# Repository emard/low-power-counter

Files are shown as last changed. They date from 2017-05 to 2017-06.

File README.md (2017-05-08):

# Low power counter with ATTINY85V

Intended for counting slow pulses which
occur once in few seconds or slower.

Counter keeps its state in EEPROM
which retains data when unpowered 
(without battery).

Counts up to 4 input channels and sends
them over 1 multiplexed output line.

Runs on 3V lithium battery like CR2032.
In standby state it enters low power mode (below 1uA),
what makes a long battery life.

Everything runs on a small AVR ATTINY85V microcontroller,
a single chip in 8-pin package.

# Input and Output

It counts every transition of the input state. It will trigger
on both rising and falling edges. So it will update counter
when input changes from logical 0 to 1 and also back from 1 to 0.

Chip ATTINY85V layout

    nRESET |1  \/  8| +3V
       IN3 |2      7| IN2
       OUT |3      6| IN1
       GND |4      5| IN0

Too fast events >10Hz will not be counted, for example mechanical
contact ringing of the input switch will be filtered out.

After each input pulse, new counter state is sent over
the serial digital line. Output is a timed bit sequence 
containing header, channel number, counter value and CRC.
Output is intended to be connected to a simple
on-off keying (OOK) 433 MHz transmitter and received remotely with
some general-purpose receiver like
[rtl_433](https://github.com/merbanan/rtl_433.git)
(mostly compatible with honeywell.c protocol decoder)
see also
[ArduinoWeatherOS](https://github.com/robwlakes/ArduinoWeatherOS)
about Manchester protocol encoding.

# Power saving issues

When designing the [circuit](/circuit/schematics.pdf) 
take into account that every current flow
draws some power, so for example when internal pull-up resistors
in the chip are enabled, each input connected to GND will draw about 
80uA which can drain CR2032 battery in 3 months.
Option is to disable internal pull-up and connect external
1Mohm pull-up resistor. It will draw 3uA per grounded input pin,
but will also be more sensitive to environmental electric noise.

During 3V battery life, voltage will drop down to about 2V.
Low-voltage version of the chip "ATTINY85V" is recommended
because it is designed to work down to 1.8V.
Normal "ATTINY85" is designed down to 2.7V but it 
seems to work at 2V though.

The output transmitter should also be designed to work with
battery voltage below 2V and have low power mode when idle.
SYN115 433MHZ ASK Transmitter Module works well.

# Todo

    [ ] Reset all counters with nRESET
    [ ] Battery voltage monitoring

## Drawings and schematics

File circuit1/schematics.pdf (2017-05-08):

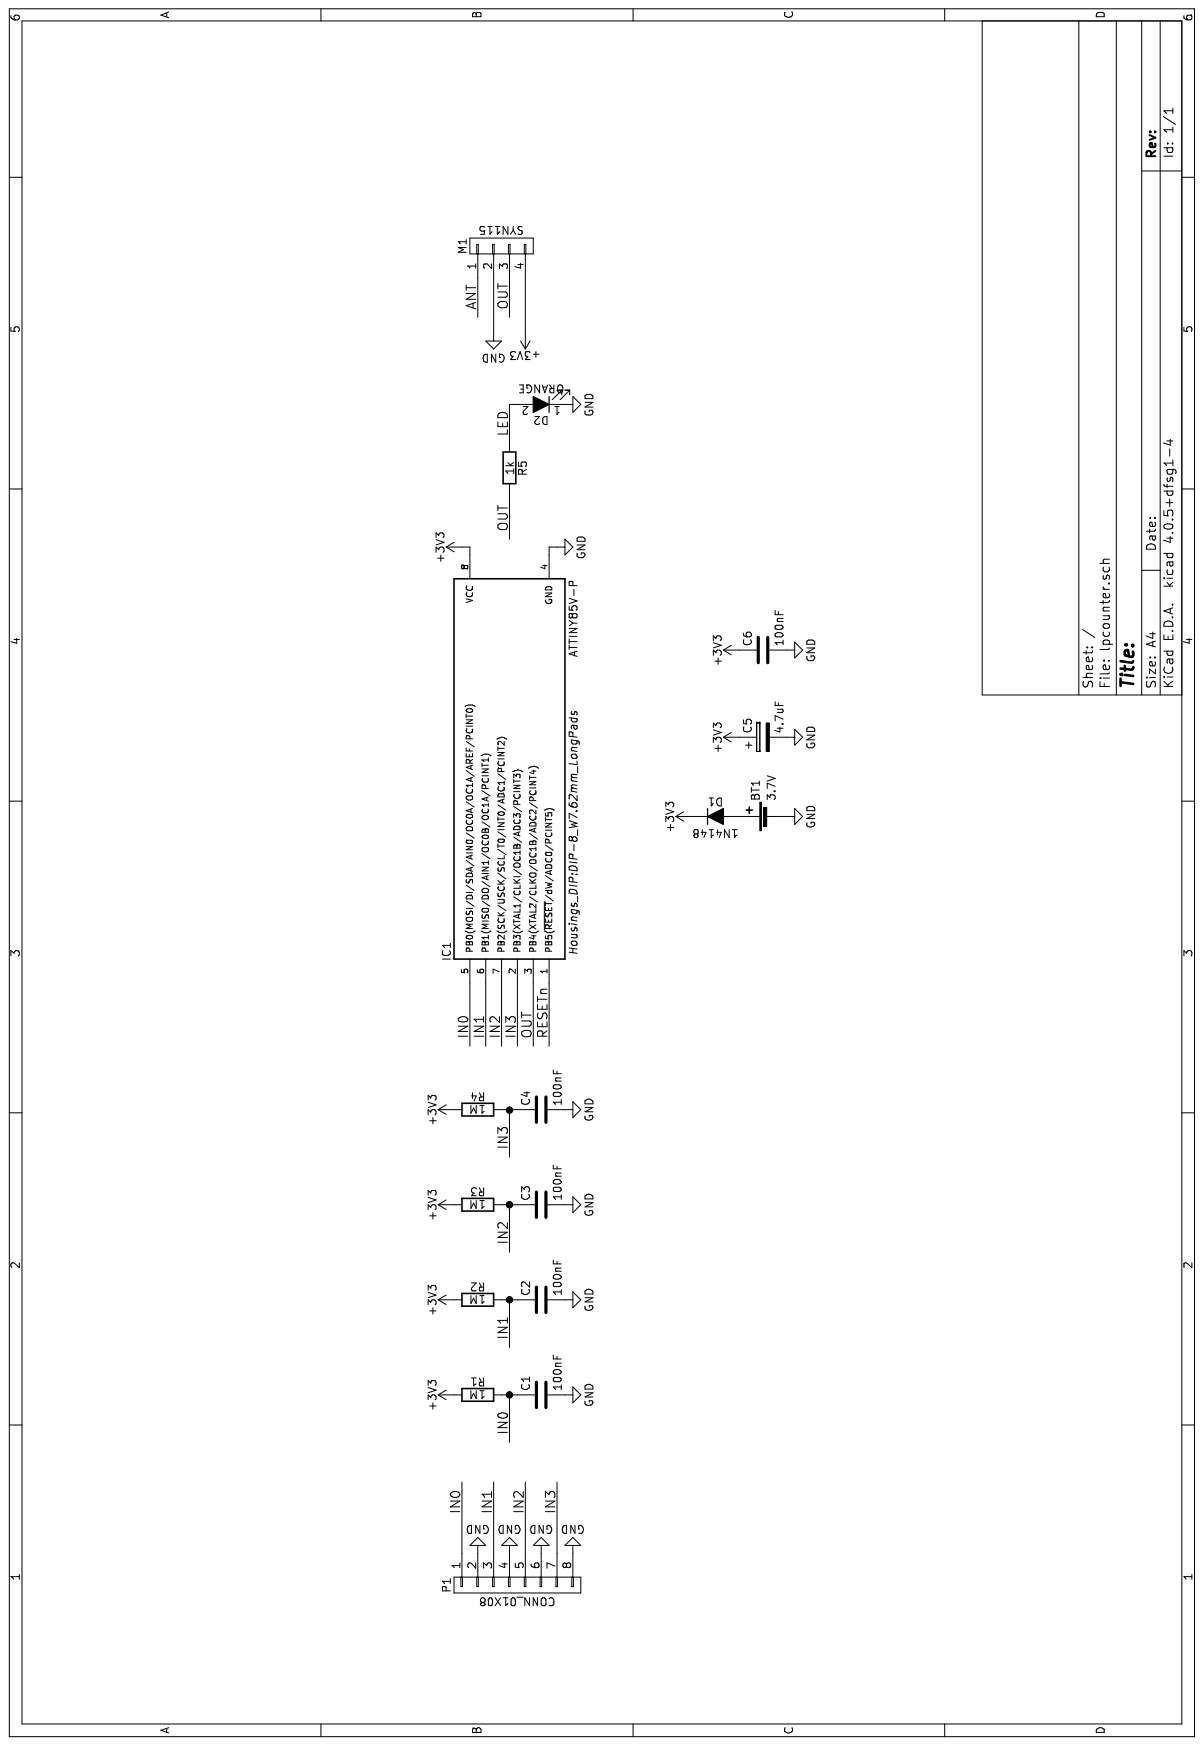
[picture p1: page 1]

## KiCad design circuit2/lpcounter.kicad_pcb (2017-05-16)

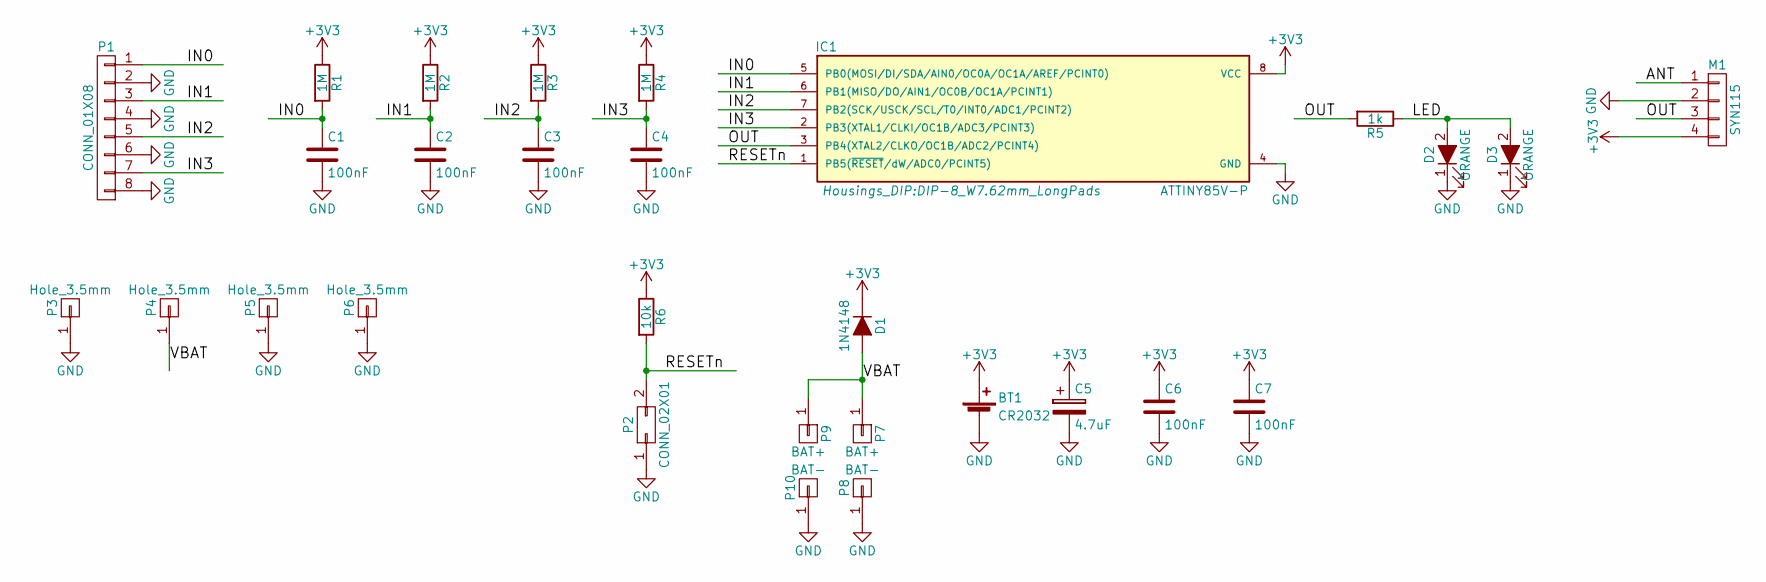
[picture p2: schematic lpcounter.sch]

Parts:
BT1: CR2032; Keystone_106_1x20mm-CoinCell
C1, C2, C3, C4, C6, C7: 100nF; C_1206_HandSoldering
C5: 4.7uF; Tantalum_Case-U_EIA-6032-15_Hand
D1: 1N4148; MiniMELF_Handsoldering
D2: ORANGE; LED-5MM
D3: ORANGE; LED_1206
IC1: ATTINY85V-P; DIP-8_W7.62mm_LongPads
M1: SYN115
P1: CONN_01X08; PhoenixContact_MSTBVA-G_08x5.08mm_Vertical
P2: CONN_02X01; Pin_Header_Straight_1x02
P3, P4, P5, P6: Hole_3.5mm; MountingHole_3.5mm_Pad
P7, P9: BAT+; Pin_Header_Straight_1x01
P8, P10: BAT-; Pin_Header_Straight_1x01
R1, R2, R3, R4: 1M; R_1206_HandSoldering
R5: 1k; R_1206_HandSoldering
R6: 10k; R_1206_HandSoldering

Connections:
+3V3: BT1.1 (+), C5.1, C6.1, C7.1, D1.1 (K), IC1.8 (VCC), M1.4, R1.1, R2.1, R3.1, R4.1, R6.1
/ANT: M1.1
/IN0: C1.1, IC1.5 (PB0(MOSI/DI/SDA/AIN0/OC0A/OC1A/AREF/PCI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), P1.1, R1.2
/IN1: C2.1, IC1.6 (PB1(MISO/DO/AIN1/OC0B/OC1A/PCINT1)), P1.3, R2.2
/IN2: C3.1, IC1.7 (PB2(SCK/USCK/SCL/T0/INT0/ADC1/PCINT2)), P1.5, R3.2
/IN3: C4.1, IC1.2 (PB3(XTAL1/CLKI/OC1B/ADC3/PCINT3)), P1.7, R4.2
/LED: D2.2 (A), D3.2 (A), R5.1
/OUT: IC1.3 (PB4(XTAL2/CLKO/OC1B/ADC2/PCINT4)), M1.3, R5.2
/RESETn: IC1.1 (PB5(~RESET~/dW/ADC0/PCINT5)), P2.2, R6.2
/VBAT: D1.2 (A), P4.1, P7.1, P9.1
GND: BT1.2 (-), C1.2, C2.2, C3.2, C4.2, C5.2, C6.2, C7.2, D2.1 (K), D3.1 (K), IC1.4 (GND), M1.2, P1.2, P1.4, P1.6, P1.8, P2.1, P3.1, P5.1, P6.1, P8.1, P10.1

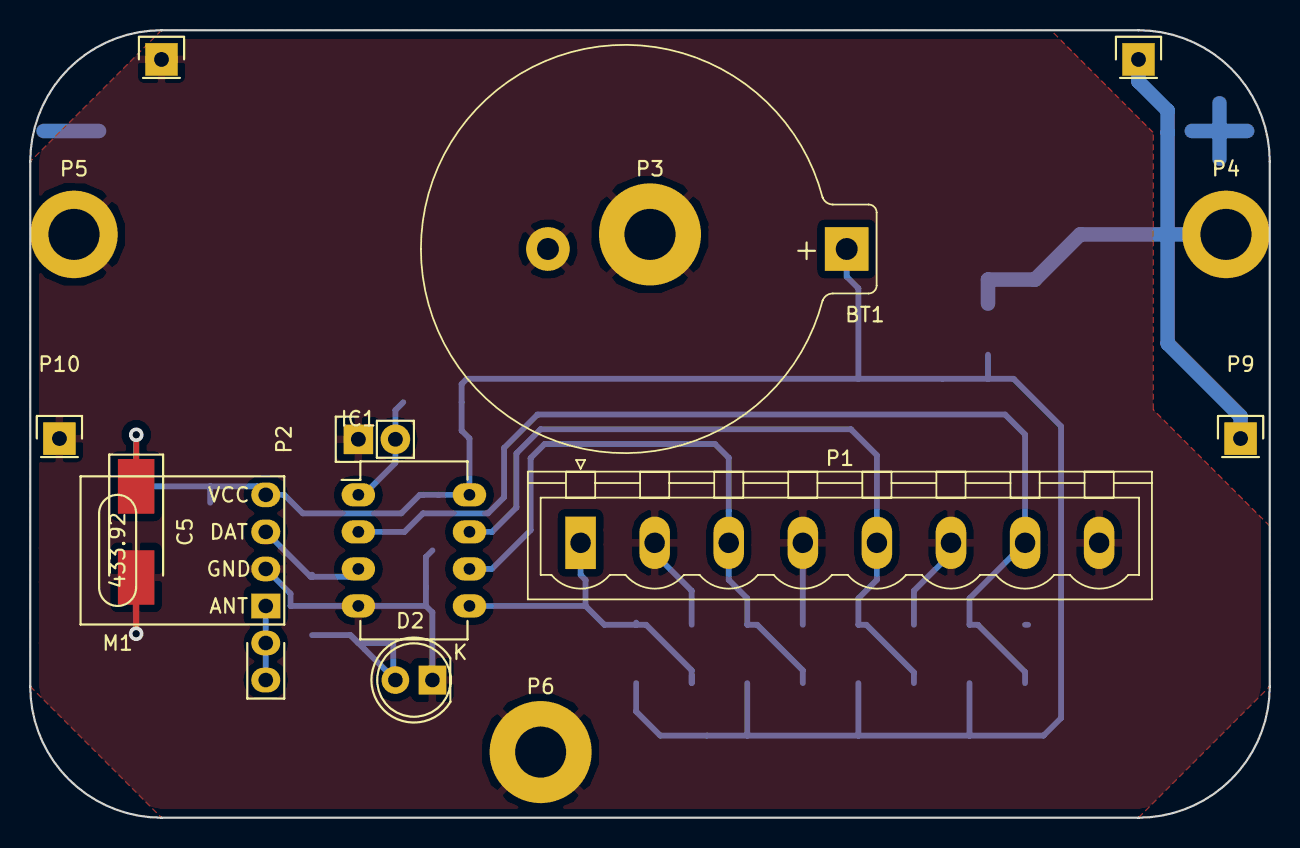
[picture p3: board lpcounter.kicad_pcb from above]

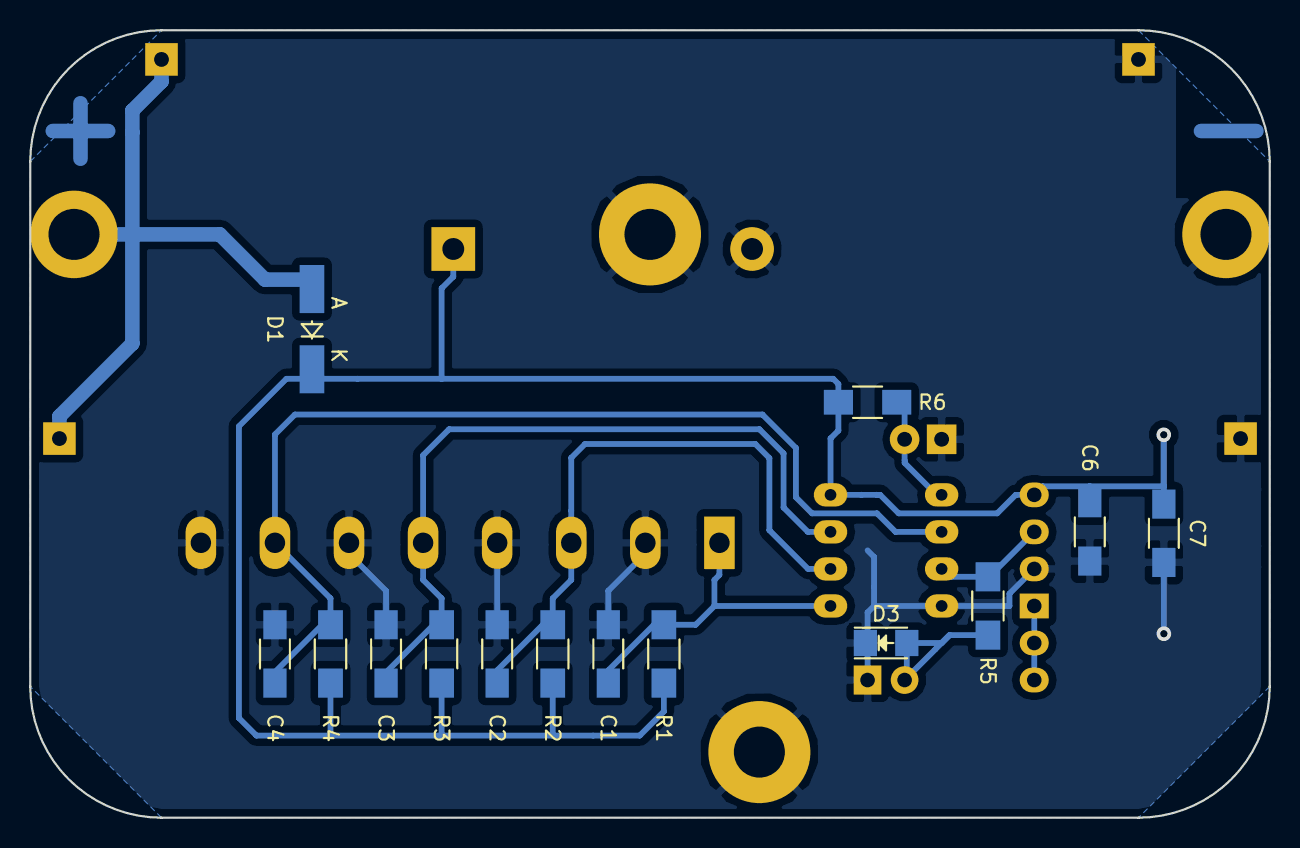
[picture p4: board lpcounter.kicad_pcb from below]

Board: 2 copper layers, 85.0 x 54.0 mm, 29 parts (14 on the bottom side), 10 nets.

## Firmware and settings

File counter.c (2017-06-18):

#include <avr/io.h> 
#include <stdlib.h>
#include <string.h>
#include <avr/interrupt.h>
#include <avr/eeprom.h>
#include <avr/sleep.h>
// #include <util/crc16.h>

#define LED (1<<PB4)
#define INPUT ((1<<PB0)|(1<<PB1)|(1<<PB2)|(1<<PB3))
#define PULLUP ((0<<PB0)|(0<<PB1)|(0<<PB2)|(0<<PB3))
#define INTERRUPT_PINS ((1<<PCINT0)|(1<<PCINT1)|(1<<PCINT2)|(1<<PCINT3))

#define ADC_DISABLE() (ADCSRA &= ~(1<<ADEN)) // disable ADC (before sleep)
#define ADC_ENABLE() (ADCSRA |= (1<<ADEN) | (1<<ADATE)) // enable continuous ADC (after sleep)
#define PIN_CHANGE_INTERRUPT_ENABLE() (GIMSK |= (1<<PCIE))
#define PIN_CHANGE_MONITOR(n) (PCMSK = n) // example: use (PCINT2 | PCINT3) to monitor PB2 and PB3 
#define PIN_CHANGE_FLAG_CLEAR() (GIFR = PCIF)

enum 
{ 
  EEPROM_BYTES = 512, // eeprom size in bytes, see datasheet
  N_CHANNELS = 4, // number of channels to track
  N_RETRANSMIT = 50, // how many times to re-transmit the message
  RETRANSMIT_DELAY1 = 200, // x100 us delay after first and subseqent odd retransmission 200->20ms
  RETRANSMIT_DELAY2 = 200, // x100 us delay after second and subsequent even retransmission 5000->500ms
  DEBOUNCE = 1000, // x100 us debounce time 200->20ms, 1000->0.1s
};

// counter data struct
struct record
{
  int32_t c[N_CHANNELS];
  uint8_t v; // battery voltage = 1.1*255/v, 77-99 high, 100-109 medium, 110-150 low
};

// calculate how many records can we store
enum
{
  N_RECORDS = EEPROM_BYTES/sizeof(struct record),
};

struct record EEMEM memory[N_RECORDS] = // storage in EEPROM
{
   { { 0,0,0,23*20, }, 1}, // initial counter values after flashing, battery voltage nonzero
};

struct record counter[1]; // one record as counter in RAM

// encoded packet to be sent, bit-slice
union packet
{
  struct
  {
    uint64_t crc:16, data:8, serial:20, unknown:4, preamble:16;
  };
  uint64_t binary;
};

uint8_t pin_state, pin_change; // ISR tracks pin state and sets bits of pin_change to 1

void record_read(struct record *r, uint8_t i)
{
  eeprom_read_block(r, &(memory[i % N_RECORDS]), sizeof(struct record));
}

void record_write(struct record *r, uint8_t i)
{
  eeprom_update_block(r, &(memory[i % N_RECORDS]), sizeof(struct record));
}

void counter_reset()
{
  uint8_t i;
  memset(counter, 0, sizeof(struct record));
  for(i = 0; i < N_RECORDS; i++)
    record_write(counter, i);
}

// find free data in eeprom
// that's first data which has 0
// also read the last non-free record
uint8_t find_free_record(struct record *r)
{
  uint8_t i;
  uint8_t nonzero_found = 0;
  struct record data[1];
  for(i = 0; i < N_RECORDS; i++)
  {
    uint8_t j, z = N_CHANNELS;
    // eeprom_read_block(data, &(memory[i % N_RECORDS]), sizeof(struct record));
    record_read(data, i);
    for(j = 0; j < N_CHANNELS; j++)
    {
      if(data->c[j] == 0)
        z--;
    }
    // all values zero -> found new free entry
    if(z == 0)
    {
      if(nonzero_found == 1)
      {
        return i;
      }
    }
    else
    {
      nonzero_found = 1;
      if(r)
        memcpy(r, data, sizeof(struct record));
    }
  }
  return 0;
}

// interrupt service routine: PIN CHANGE 0 interrupt
// on attiny84 it covers 8 input pins PA 0-7
// there also exists PIN CHANGE 1 interrupt which
// covers another 4 input pins PB 0-3
// on attiny85 only PIN CHANGE 0 exists
ISR(PCINT0_vect)
{
  uint8_t pin_current = PINB & INPUT;
  pin_change |= pin_current ^ pin_state;
  pin_state = pin_current;
  // executing ISR will automatically clear its interrupt flag.
  // it is not neccessary to manually clear interrupt flag:
  // PIN_CHANGE_FLAG_CLEAR();
}

// store the counter using eeprom record storage
void store_counter()
{
 uint8_t j, k;

 j = find_free_record(NULL);
 record_write(counter, j);
 // next position, wraparound
 if(++j >= N_RECORDS)
   j = 0;
 // create 0-delimiter
 struct record delimiter[1];
 delimiter->v = 0;
 for(k = 0; k < N_CHANNELS; k++)
   delimiter->c[k] = 0;
 // write 0-delimiter to next position
 record_write(delimiter, j);
}

uint16_t crc16_ccitt(uint8_t const message[], unsigned nBytes, uint16_t polynomial, uint16_t init) {
    uint16_t remainder = init;
    unsigned byte, bit;

    for (byte = 0; byte < nBytes; ++byte) {
        remainder ^= message[byte] << 8;
        for (bit = 0; bit < 8; ++bit) {
            if (remainder & 0x8000) {
                remainder = (remainder << 1) ^ polynomial;
            }
            else {
                remainder = (remainder << 1);
            }
        }
    }
    return remainder;
}

void update_crc(union packet *p)
{
  uint8_t i;
  uint8_t bb[6], *b;
  b = (uint8_t *) &(p->binary);
  for(i = 0; i < 6; i++)
    bb[i] = ~b[7-i];
  p->crc = ~crc16_ccitt(bb, 6, 0x8005, 0xfffe);
}

void transmit(uint8_t i)
{
  uint8_t j;
  union packet tx;

  // Construct the 64-bit TX packet
  tx.preamble = ~0xFFFE;
  tx.unknown = ~i;
  // tx.serial = 0x55664L;
  // tx.data = 0x3F;
  // tx.crc = 0x277D;
  tx.serial = ~(counter->c[i]); // counter value
  tx.data = ~(counter->v); // battery voltage = 1.1V*255/this_value
  update_crc(&tx);

  // use timer0 
  TCNT0 = 0;
  OCR0A = 135; // us (nomial value 140 us)
  TCCR0A = 2; // ctc mode - TCNT0 runs from 0 to OCR0A
  TCCR0B = 1; // prescaler 1 (clk), 2 (clk/8), 3 (clk/64), 4 (clk/256), 5 (clk/1024)
 
  TIFR = 1<<OCF0A; // reset timer overflow interrupt flag
 
  // blink LED send binary counter, send LSB first
  for(j = 0; j < 64; j++) // send 64-bit packet manchester encoded, MSB first
  {
    // calculate LED output state in advance
    uint8_t ledstate = (tx.binary & (1ULL<<63)) != 0 ? PORTB | PULLUP | LED : (PORTB | PULLUP) & ~LED; // MSB
    while((TIFR & (1<<OCF0A)) == 0); // wait for interrupt flag
    TIFR = 1<<OCF0A; // reset timer overflow interrupt flag
    PORTB = ledstate;
    tx.binary <<= 1; // shift next bit
    while((TIFR & (1<<OCF0A)) == 0); // wait for interrupt flag
    TIFR = 1<<OCF0A; // reset timer overflow interrupt flag
    PINB = LED; // invert the led and wait again -> manchester encoding
  }
  while((TIFR & (1<<OCF0A)) == 0); // wait for interrupt flag
  TIFR = 1<<OCF0A; // reset timer overflow interrupt flag
  PORTB &= ~LED; // led OFF
}

void update_pin_state()
{
  uint8_t i;
  pin_state = 0;
  for(i = N_CHANNELS-1; i != 0xff; i--)
  {
    pin_state <<= 1;
    pin_state |= counter->c[i] & 1; // LSB of the counter is the pin state
  }
}

// delay = n * 100 us
void delay(uint16_t x100us)
{
  uint16_t j;
  TCNT0 = 0;
  OCR0A = 100; // us
  TCCR0A = 2;
  TCCR0B = 1; // prescaler 1 (clk)
 
  TIFR = 1<<OCF0A; // reset timer overflow interrupt flag
  for(j = 0; j < x100us; j++)
  {
    while((TIFR & (1<<OCF0A)) == 0); // wait for interrupt flag
    TIFR = 1<<OCF0A; // reset timer overflow interrupt flag
  }
}

void main()
{
 // as early as possible, check the MCUSR to detect external reset
 // upon external reset, reset the EEPROM counter state
 #if 0
 uint8_t mcusr = MCUSR;
 MCUSR = 0; // clear it
 if((mcusr | EXTRF) != 0) // external reset -- clear eeprom
   counter_reset();
 #endif

 ADMUX = (0<<REFS0) | (1<<ADLAR) | (12<<MUX0); // ADC measure VCC voltage against internal 1.1V reference
 // ADLAR set to left-adjust result suitable for 8-bit reading

 set_sleep_mode(SLEEP_MODE_PWR_DOWN);

 delay(10000); // wait a moment for power to become stable (switch glitch...)
 
 DDRB = LED; // only LED output, other pins input
 PORTB = PULLUP; // pullup enable on input pins, led OFF

 find_free_record(counter);
 update_pin_state(); // read pin state from last record in eeprom

 PIN_CHANGE_FLAG_CLEAR();
 PIN_CHANGE_INTERRUPT_ENABLE();
 PIN_CHANGE_MONITOR(INTERRUPT_PINS); // this is PB0-PB3 inputs
 // should already set monitored pin as input and enable its pull up
 PIN_CHANGE_FLAG_CLEAR();

 // initialize pin change, compare stored state to current state
 pin_change = (PINB & INPUT) ^ pin_state;
 
 for(;;)
 {
   #if 1
   ADC_ENABLE();
   ADCSRB = 0<<ADTS0; // for free-running mode
   uint8_t j; // loop counter
   uint8_t tx = 0; // Bitmap having '1' for each counter changed. Used ad request to transmit
   delay(DEBOUNCE); // wait for input to stabilize and ISR to set pin_change
   ADCSRA |= 1<<ADSC; // Start measuring battery voltage
   while(pin_change != 0)
   {
     uint8_t change = pin_change, m = 1; // m is shifting 1-bit bitmask
     uint8_t new_pin_state = PINB & INPUT;

     for(j = 0; j < N_CHANNELS; j++)
     {
       if( (change & m) != 0 || ((new_pin_state ^ pin_state) & m) != 0 )
       {
         counter->c[j]++;
         update_pin_state();
         if( ((new_pin_state ^ pin_state) & m) != 0)
         {
           counter->c[j]++;
           update_pin_state();
         }
         cli();
         pin_change &= ~m; // clear pin change bit (change serviced)
         sei();
         tx |= m; // request to transmit this bit
       }
       m <<= 1; // upshift mask
     }
     delay(DEBOUNCE); // wait for pins to change again
   }

   if(tx != 0)
   {
     PORTB |= LED; // wake up the transmitter
     delay(1); // 0.1 ms pulse wakeup starts
     PORTB &= ~LED;
     // while( (ADCSRA & (1<<ADSC)) != 0 ); // wait until battery voltage measurement is done 
     // ADCL reading must be before reading ADCH
     counter->v = ADCH; // reading ADCH unlocks both ADCL and ADCH
     store_counter();
     // delay(100); // wait until transmitter wakes up completely
     for(j = 0; j < N_CHANNELS; j++)
     {
       if( (tx & 1) != 0 )
       {
         int i;
         for(i = 0; i < N_RETRANSMIT; i++)
         {
           // spacing between retransmissions
           delay( (i & 1) == 0 ? RETRANSMIT_DELAY1 : RETRANSMIT_DELAY2); // 20/500 ms delay
           cli();
           transmit(j);
           sei();
         }
       }
       tx >>= 1;
     }
   }
   #else
   // this works for single counter
   counter->c[0]++;
   store_counter();
   transmit(0);
   #endif

   ADC_DISABLE();
 
   cli();
   if(1 == 1)
   {
     sleep_enable();
     sei();
     sleep_cpu();
     sleep_disable();
   }
   // if we don't have ISR registered,
   // we need to manually clear interrupt flag:
   // PIN_CHANGE_FLAG_CLEAR();
   sei();
 }
}

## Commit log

2017-04-24 untested code to wake from sleep at interrupt
2017-04-24 empty pin change interrupt service routine
2017-04-24 getting it to compile and upload to device
2017-04-24 eeprom writes something at 1st location but doesn't advance to next record
    [counter.c]
2017-04-24 device now enters power down mode, draws around 1uA
2017-04-24 pin change interrupt works on PB0 only
2017-04-25 OK, pin change wakeup seems to work. Note that weak pullup when enabled and pin held down will consume 80uA
2017-04-25 ISR is actually not needed, input switch monitoring will be slow
2017-04-25 tracking each pin, but unreliable
2017-04-25 untested attempt to use ISR to track pin change
2017-04-25 unsupported use of timer overflow to precisely time output transmit sequence
2017-04-25 good input pulse detection timer not working
    [counter.c]
2017-04-25 timer seems to work now, missing 1<<
    [counter.c]
2017-04-25 enabling and slightly bugfixing code for interrupt pin state tracking and counting
    [counter.c]
2017-04-26 untested clearing of the eeprom on external reset
    [counter.c]
2017-04-26 disabling erase counter after reset - it erases counter on every power up
    [counter.c]
2017-04-27 detect pin change during power off
2017-04-28 trying to improve speed of counting, counter loop will accumulate changes when pulses come one after another, taking de-bounce delay into account. When pulses stop coming within some delay time, it w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
2017-04-28 speeding up the timer
2017-04-29 prolong wakeup pulse to 200us and shorten retransmit pause to 15 ms
    [counter.c]
2017-04-29 delay() bugfixed to work with 16-bit paramter
    [counter.c]
2017-04-29 Issue wakeup pulse only before first transmission. Disable interrupt during transmit() to improve bit timing.
    [counter.c]
2017-04-29 configure pullup resistors for each input pin
2017-04-29 readme update, count frequency about 10Hz
2017-04-30 readme update, sume power saving tips
2017-05-02 readme update, need to monitor battery voltage
2017-05-02 battery voltage monitoring and reporting - untested
2017-05-02 fix ADC setting to measure battery voltage
    [counter.c]
2017-05-02 comments on how to calculate battery voltage
2017-05-02 comment approx battery values
2017-05-02 free running ADC
2017-05-02 clear ADCSRB register for ADC free-running
2017-05-08 Schematics and rough PCB in KiCAD
    [lpcounter.kicad_pcb, lpcounter.sch]
2017-05-08 proper battery holder for CR2032
    [lpcounter.kicad_pcb, lpcounter.sch]
2017-05-08 readme: link to schematics PDF
2017-05-08 schematics PDF
2017-05-08 updating PCB
    [lpcounter.kicad_pcb, lpcounter.sch]
2017-05-08 fully routed
    [lpcounter.kicad_pcb, lpcounter.sch]
2017-05-08 small chamges, optimizing routes
    [lpcounter.kicad_pcb]
2017-05-09 correct footprint for SYN115, 4 screw holes, optimizing PCB drawing 18650 battery outiline
    [lpcounter.kicad_pcb, lpcounter.sch]
2017-05-09 3V battery connected direct, 3.7V battery connect in series with diode 1N4147
    [lpcounter.kicad_pcb, lpcounter.sch]
2017-05-10 placeholder for both SMD and TH LED
    [lpcounter.kicad_pcb, lpcounter.sch]
2017-05-11 drawing ABC plastic box and 18650 battery footprint for possible PCB which fits in such box
    [lpcounter.kicad_pcb]
2017-05-13 another PCB, same circuit but fit into ABC box
    [lpcounter.kicad_pcb, lpcounter.sch]
2017-05-13 optimizing PCB
    [lpcounter.kicad_pcb, lpcounter.sch]
2017-05-13 changing pushbutton to jumper
    [lpcounter.kicad_pcb, lpcounter.sch]
2017-05-13 increase PCB to fully fit into ABC box, multiple battery contacts
    [lpcounter.kicad_pcb, lpcounter.sch]
2017-05-15 increase clearance in design rules
    [lpcounter.kicad_pcb]
2017-05-15 preparation for fabrication moving electronic parts away from the edge
    [lpcounter.kicad_pcb]
2017-05-15 holes update
    [lpcounter.kicad_pcb, lpcounter.sch]
2017-05-15 update gerbers
    [lpcounter-B.Cu.gbl, lpcounter-B.Fab.gbr, lpcounter-B.Mask.gbs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]
2017-05-16 small PCB optimizations, moving screw connector away from CR2032 battery add top zone layer and capacitor on top
    [lpcounter-B.Cu.gbl, lpcounter-B.Fab.gbr, lpcounter-B.Mask.gbs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]
2017-06-18 removing weak pullups form all inputs. Larger pullup (1M) is externally mounted on PCB
